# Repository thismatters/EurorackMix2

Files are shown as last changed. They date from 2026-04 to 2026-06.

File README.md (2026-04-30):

# Mix

A simple mixing circuit which allows adjustment of each input before combining to a single output. Really simple.

The KiCAD project here uses the library/footprints [found in my companion repo](https://github.com/thismatters/EurorackKiCAD).

## Width

6hp

## Inputs

- Four signal jack
- Four signal knobs

## Outputs

One signal jack with combined output

## Vendors

There are part numbers in the [BOM](mix2.csv) for many of the parts (not for basic passives though) at the following vendors:

* [Mouser](https://www.mouser.com): Needs no introduction. Get your ICs from here (or [digikey](https://www.digikey.com)).
* [Tayda Electronics](https://www.taydaelectronics.com/): Good supplier for passive components; audio jacks, and potentiometers. Their audio jacks are slightly smaller than the thonkiconn from thonk.
* [Love My Switches](https://lovemyswitches.com/): Has [really good knobs](https://lovemyswitches.com/anodized-aluminum-knob-the-lo-fi-1-4-smooth-shaft-12-5mm-od/) to go on those potentiometers!
* [OSHPark](https://oshpark.com/): Fast and (relatively) cheap PCB manufacturer. Prototype run pending.

## Changelog

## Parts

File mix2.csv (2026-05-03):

Reference | Qty | Value | Footprint | Vendor | PartNum
C1,C2 | 2 | 22u 50V | Capacitor_THT:CP_Radial_D5.0mm_P2.50mm
C3 | 1 | 100n | Capacitor_SMD:C_0805_2012Metric
D1,D2 | 2 | BAT54S | Package_TO_SOT_SMD:SOT-23 | Mouser | 863-BAT54SLT1G
J1 | 1 | Conn_02x05_Odd_Even | Eurorack:PinHeader_2x05_P2.54mm_Vertical | Tayda | A-2939
J2 | 1 | in0 | Eurorack:AudioJack2_Tayda_A-2566 | Tayda | A-2566
J3 | 1 | in1 | Eurorack:AudioJack2_Tayda_A-2566 | Tayda | A-2566
J4 | 1 | in2 | Eurorack:AudioJack2_Tayda_A-2566 | Tayda | A-2566
J5 | 1 | in3 | Eurorack:AudioJack2_Tayda_A-2566 | Tayda | A-2566
J6 | 1 | out | Eurorack:AudioJack2_Tayda_A-2566 | Tayda | A-2566
R1,R2 | 2 | 10 | Resistor_SMD:R_0805_2012Metric
R3,R4,R5,R6,R7,R8,R9,R10 | 8 | 100K | Resistor_SMD:R_0805_2012Metric
RV1,RV2,RV3,RV4 | 4 | A250K | Eurorack:Potentiometer_RV16AF-41-15R1
U1 | 1 | TL072 | Package_SO:SOIC-8_3.9x4.9mm_P1.27mm | Mouser | 595-TL072CDR

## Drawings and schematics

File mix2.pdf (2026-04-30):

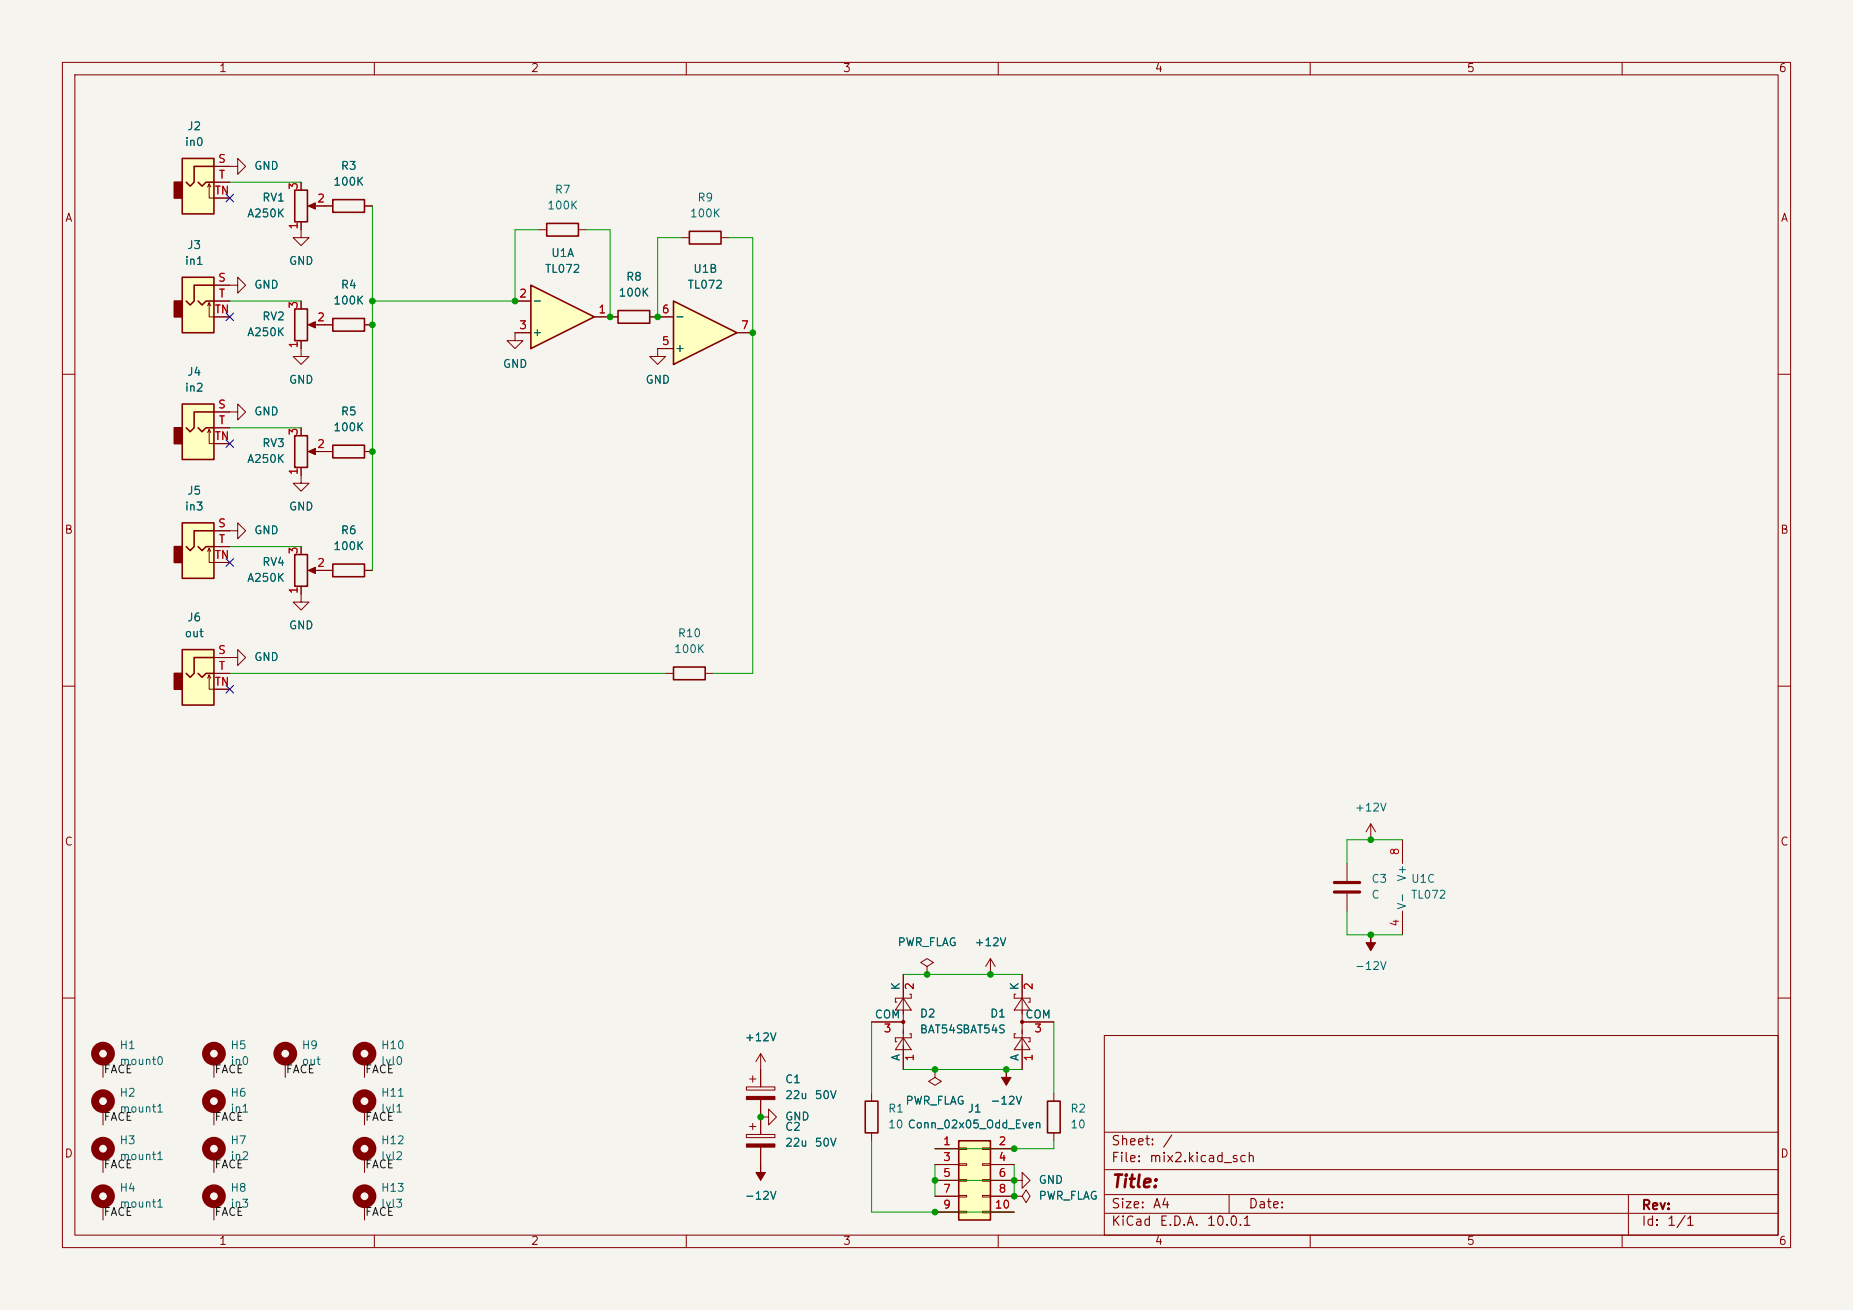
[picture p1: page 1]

5 5 | 6 6
7 7 | 8 8

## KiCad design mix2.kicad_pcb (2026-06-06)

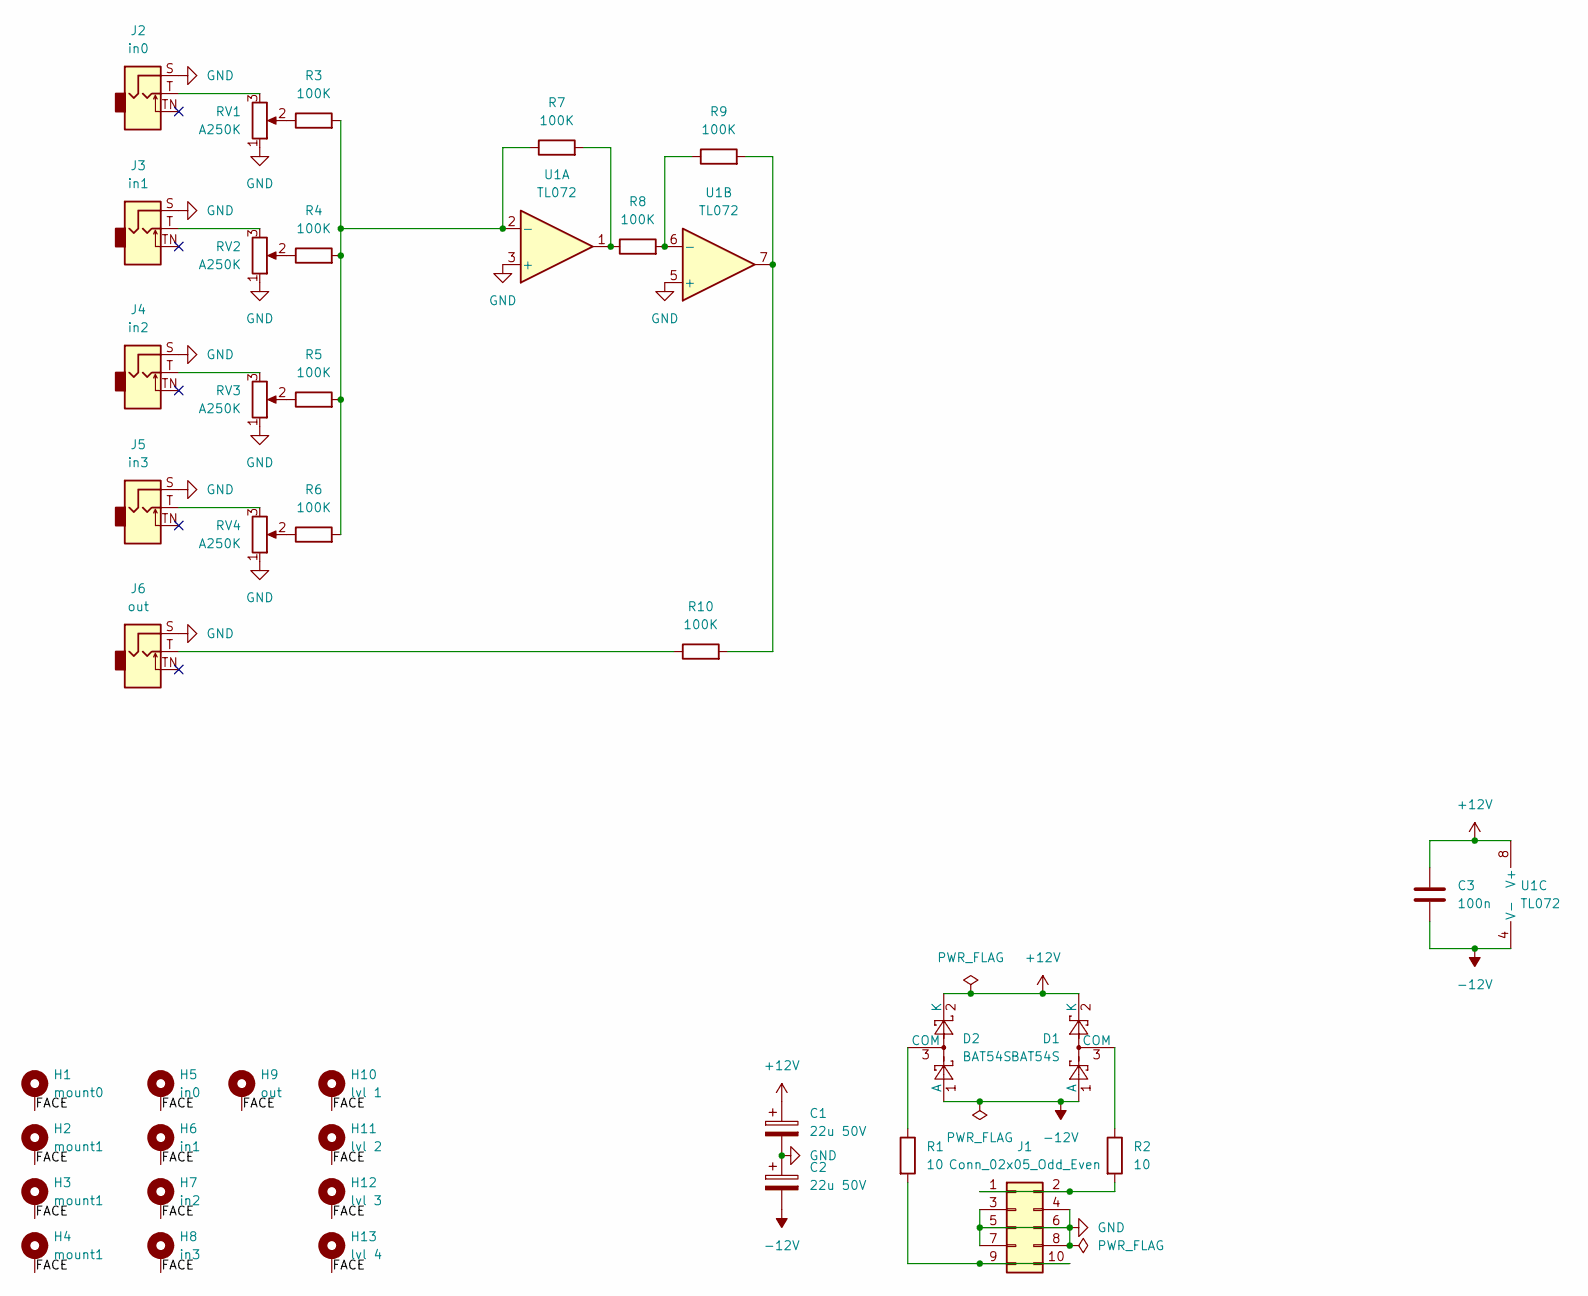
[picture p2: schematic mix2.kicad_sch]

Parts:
C1, C2: 22u 50V; CP_Radial_D5.0mm_P2.50mm
C3: 100n; C_0805_2012Metric
D1, D2: BAT54S; SOT-23; PartNum 863-BAT54SLT1G
H1: mount0; Mech-MountingHole
H2, H3, H4: mount1; Mech-MountingHole
H5: in0; Mech-AudioJack-Hole-Input
H6: in1; Mech-AudioJack-Hole-Input
H7: in2; Mech-AudioJack-Hole-Input
H8: in3; Mech-AudioJack-Hole-Input
H9: out; Mech-AudioJack-Hole-Output
H10: lvl 1; Mech-Potentiometer-Hole_level
H11: lvl 2; Mech-Potentiometer-Hole_level
H12: lvl 3; Mech-Potentiometer-Hole_level
H13: lvl 4; Mech-Potentiometer-Hole_level
J1: Conn_02x05_Odd_Even; PinHeader_2x05_P2.54mm_Vertical; PartNum A-2939
J2: in0; AudioJack2_Tayda_A-2566; PartNum A-2566
J3: in1; AudioJack2_Tayda_A-2566; PartNum A-2566
J4: in2; AudioJack2_Tayda_A-2566; PartNum A-2566
J5: in3; AudioJack2_Tayda_A-2566; PartNum A-2566
J6: out; AudioJack2_Tayda_A-2566; PartNum A-2566
R1, R2: 10; R_0805_2012Metric
R3, R4, R5, R6, R7, R8, R9, R10: 100K; R_0805_2012Metric
RV1, RV2, RV3, RV4: A250K; Potentiometer_RV16AF-41-15R1
U1: TL072; SOIC-8_3.9x4.9mm_P1.27mm; PartNum 595-TL072CDR

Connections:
+12V: C1.1, C3.1, D1.2 (K), D2.2 (K), U1.8 (V+)
-12V: C2.2, C3.2, D1.1 (A), D2.1 (A), U1.4 (V-)
/FACE: H1.1 (1_1), H2.1 (1_1), H3.1 (1_1), H4.1 (1_1), H5.1 (1_1), H6.1 (1_1), H7.1 (1_1), H8.1 (1_1), H9.1 (1_1), H10.1 (1_1), H11.1 (1_1), H12.1 (1_1), H13.1 (1_1)
GND: C1.2, C2.1, J1.3, J1.4, J1.5, J1.6, J1.7, J1.8, J2.S, J3.S, J4.S, J5.S, J6.S, RV1.1, RV2.1, RV3.1, RV4.1, U1.3 (+), U1.5 (+)
unnamed: D1.3 (COM), R2.1
unnamed: D2.3 (COM), R1.1
unnamed: J1.1, J1.2, R2.2
unnamed: J1.9, J1.10, R1.2
unnamed: J2.T, RV1.3
unnamed: J3.T, RV2.3
unnamed: J4.T, RV3.3
unnamed: J5.T, RV4.3
unnamed: J6.T, R10.1
unnamed: R3.1, RV1.2
unnamed: R4.1, RV2.2
unnamed: R5.1, RV3.2
unnamed: R6.1, RV4.2
unnamed: R7.2, R8.1, U1.1
unnamed: R9.2, R10.2, U1.7
unnamed: R3.2, R4.2, R5.2, R6.2, R7.1, U1.2 (-)
unnamed: R8.2, R9.1, U1.6 (-)

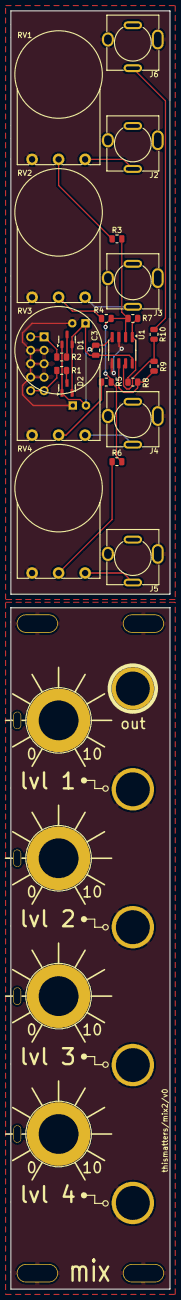
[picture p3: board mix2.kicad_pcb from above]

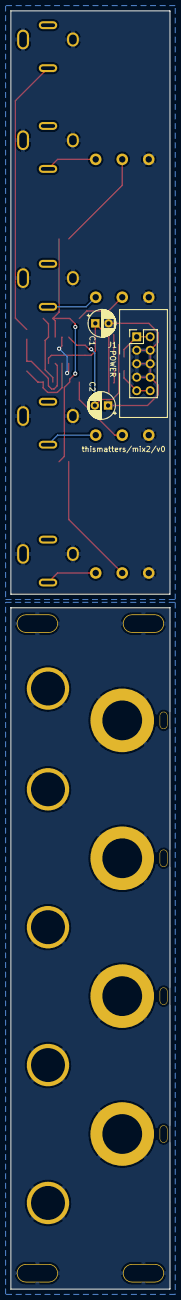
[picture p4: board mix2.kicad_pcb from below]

Board: 2 copper layers, 30.0 x 241.0 mm, 39 parts (3 on the bottom side), 21 nets.

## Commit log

2026-04-30 add schematic
2026-05-03 add bom
    [mix2.csv]
2026-05-03 fix bom issues
    [mix2.csv, mix2.kicad_pcb, mix2.kicad_sch]
2026-06-06 fix alignment for manu
    [mix2.kicad_pcb]
